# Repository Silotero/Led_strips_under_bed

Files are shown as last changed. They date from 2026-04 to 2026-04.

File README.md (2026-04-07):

# Led_strips_under_bed
Led strips that lights up according to the output of distance sensors.

The project uses 8 of HC-SR04 ultrasonic distance sensors to measure the distance beetween a detected project. They are separated into 2 zones, 4 sensors each. The 2 zones are at a 90 deegre angle (on a corner). Appropriate leds on the 2 led strips light up according to the readout of the sensors. There are 4 zones according to the distance:
-more than 115 cm - nothing lights up
-beetween 85 cm and 115 cm - light up blue
-beetween 55 cm and 85 cm - light up green
-beetween 22 cm and 55 cm - light up red

Everything is controlled via Atmega328p. The led strips are of WS2813 type.

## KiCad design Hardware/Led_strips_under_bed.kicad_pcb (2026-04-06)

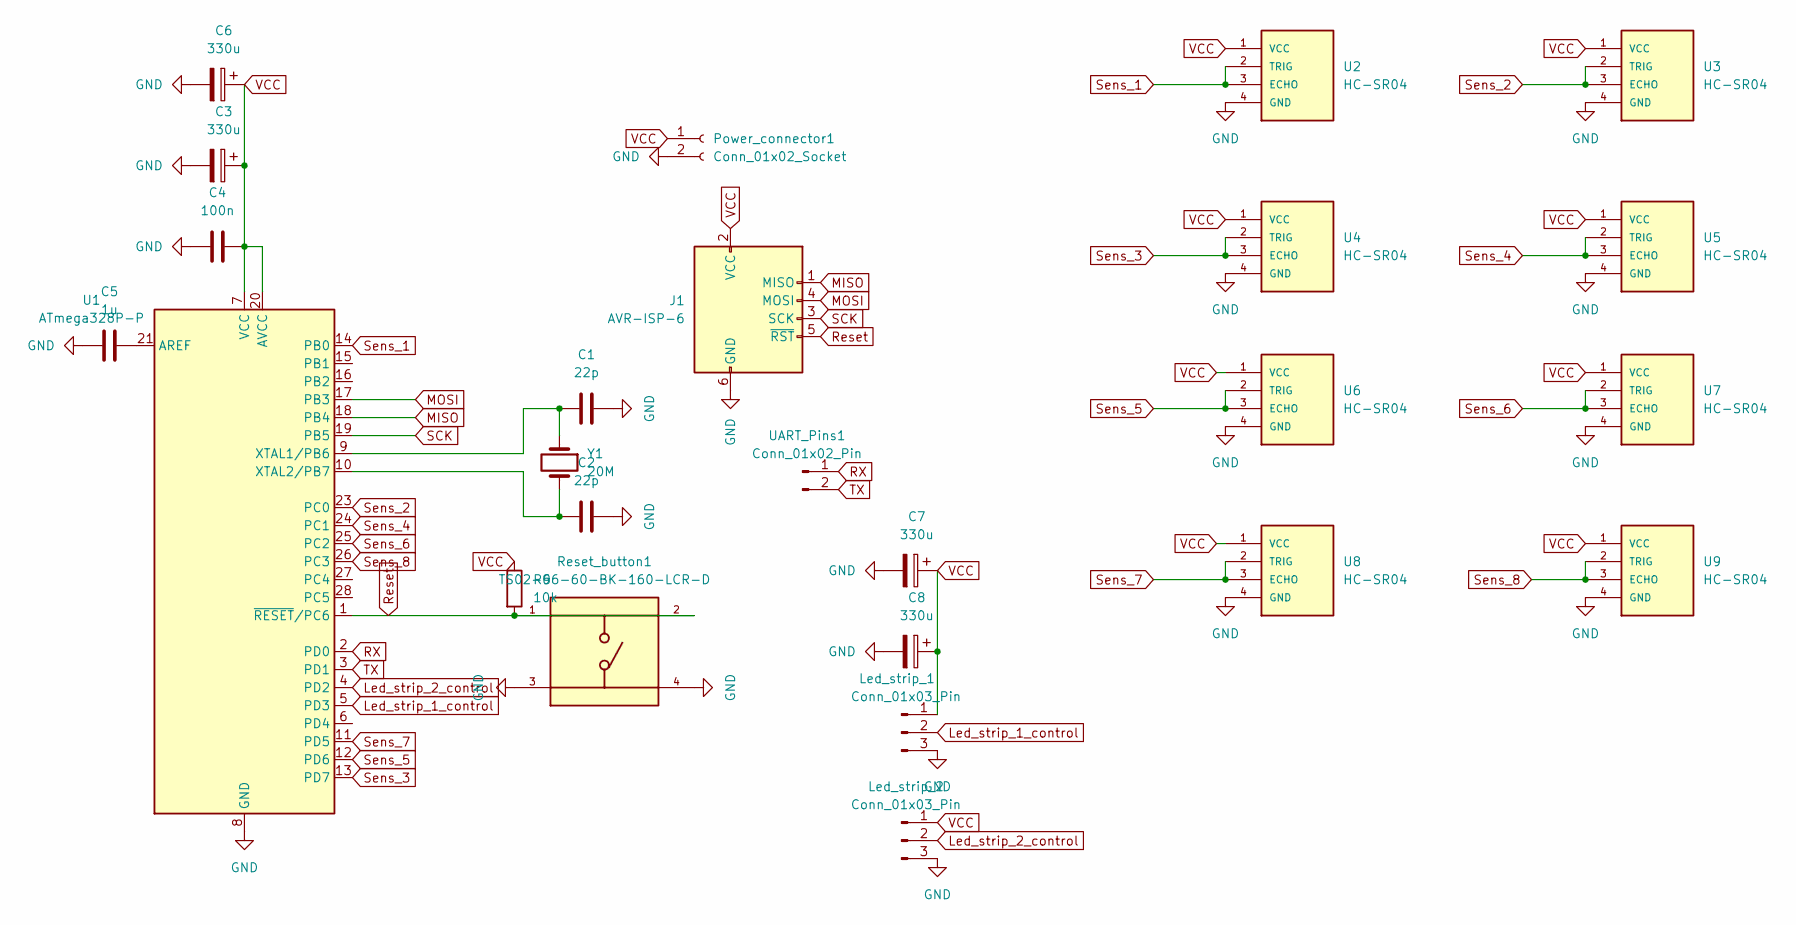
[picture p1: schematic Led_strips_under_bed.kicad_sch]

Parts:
C1, C2: 22p; C_0603_1608Metric
C3, C6, C7, C8: 330u; CP_Radial_D6.3mm_P2.50mm
C4: 100n; C_0603_1608Metric
C5: 1u; C_0603_1608Metric
J1: AVR-ISP-6; IDC-Header_2x03_P2.54mm_Vertical
Led_strip_1, Led_strip_2: Conn_01x03_Pin; PinHeader_1x03_P2.54mm_Vertical
Power_connector1: Conn_01x02_Socket; PinSocket_1x02_P2.54mm_Vertical
R9: 10k; R_0805_2012Metric
Reset_button1: TS02-66-60-BK-160-LCR-D; SW_TS02-66-60-BK-160-LCR-D; PARTREV 1.0
U1: ATmega328P-P; DIP-28_W7.62mm
U2, U3, U4, U5, U6, U7, U8, U9: HC-SR04; XCVR_HC-SR04
UART_Pins1: Conn_01x02_Pin; PinHeader_1x02_P2.54mm_Vertical
Y1: 20M; Resonator-2Pin_W7.0mm_H2.5mm

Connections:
GND: C1.2, C2.2, C3.2, C4.2, C5.2, C6.2, C7.2, C8.2, J1.6 (GND), Led_strip_1.3, Led_strip_2.3, Power_connector1.2, Reset_button1.3, Reset_button1.4, U1.8 (GND), U1.22 (GND), U2.4 (GND), U3.4 (GND), U4.4 (GND), U5.4 (GND), U6.4 (GND), U7.4 (GND), U8.4 (GND), U9.4 (GND); also elsewhere on the board
Led_strip_1_control: Led_strip_1.2, U1.5 (PD3)
Led_strip_2_control: Led_strip_2.2, U1.4 (PD2)
MISO: J1.1 (MISO), U1.18 (PB4)
MOSI: J1.4 (MOSI), U1.17 (PB3)
unnamed: C5.1, U1.21 (AREF)
unnamed: C1.1, U1.9 (XTAL1/PB6), Y1.1
unnamed: C2.1, U1.10 (XTAL2/PB7), Y1.2
RX: U1.2 (PD0), UART_Pins1.1
Reset: J1.5 (~RST), R9.2, Reset_button1.1, Reset_button1.2, U1.1 (~RESET/PC6); also elsewhere on the board
SCK: J1.3 (SCK), U1.19 (PB5)
Sens_1: U1.14 (PB0), U2.2 (TRIG), U2.3 (ECHO)
Sens_2: U1.23 (PC0), U3.2 (TRIG), U3.3 (ECHO)
Sens_3: U1.13 (PD7), U4.2 (TRIG), U4.3 (ECHO)
Sens_4: U1.24 (PC1), U5.2 (TRIG), U5.3 (ECHO)
Sens_5: U1.12 (PD6), U6.2 (TRIG), U6.3 (ECHO)
Sens_6: U1.25 (PC2), U7.2 (TRIG), U7.3 (ECHO)
Sens_7: U1.11 (PD5), U8.2 (TRIG), U8.3 (ECHO)
Sens_8: U1.26 (PC3), U9.2 (TRIG), U9.3 (ECHO)
TX: U1.3 (PD1), UART_Pins1.2
VCC: C3.1, C4.1, C6.1, C7.1, C8.1, J1.2 (VCC), Led_strip_1.1, Led_strip_2.1, Power_connector1.1, R9.1, U1.7 (VCC), U1.20 (AVCC), U2.1 (VCC), U3.1 (VCC), U4.1 (VCC), U5.1 (VCC), U6.1 (VCC), U7.1 (VCC), U8.1 (VCC), U9.1 (VCC)

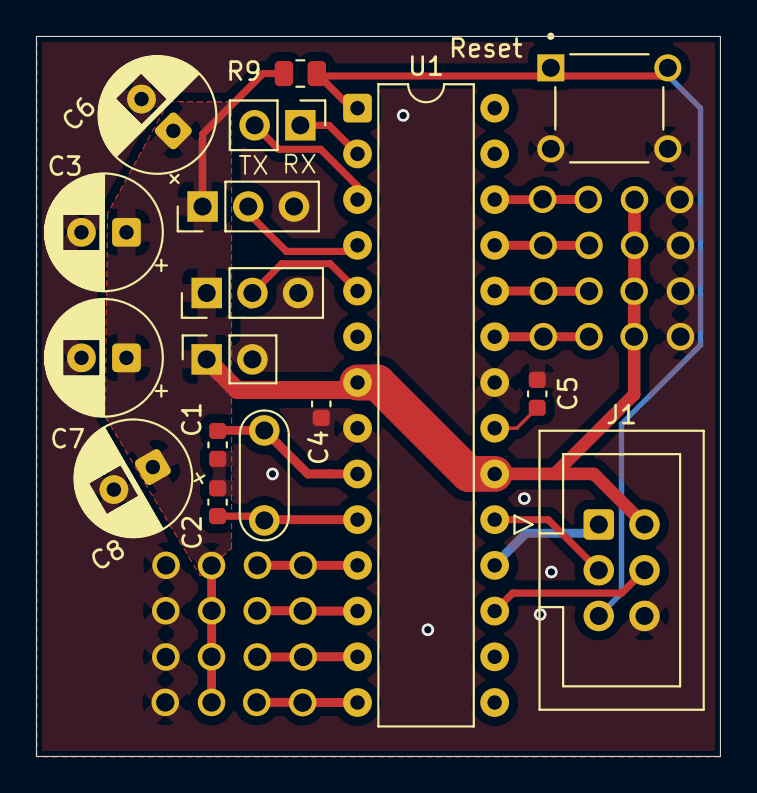
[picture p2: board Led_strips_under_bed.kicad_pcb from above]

Board: 2 copper layers, 38.0 x 40.0 mm, 25 parts (0 on the bottom side), 21 nets.

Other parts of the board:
Reset: TS02-66-60-BK-160-LCR-D; SW_TS02-66-60-BK-160-LCR-D

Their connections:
GND: Reset.3, Reset.4; also elsewhere on the board
Reset: Reset.1, Reset.2; also elsewhere on the board

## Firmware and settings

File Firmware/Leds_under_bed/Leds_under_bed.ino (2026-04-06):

#ifndef F_CPU
#define F_CPU 20000000UL
#endif
#include <avr/io.h>
#include <util/delay.h>
#include <stdbool.h>
#include <FastLED.h>
#include <UART_w_c.h>
#include <stdio.h>

#define NUM_LEDS 60 // number of used leds
#define DATA_PIN_STRIP_1 2 // pin for the led strip control
#define DATA_PIN_STRIP_2 3 // pin for the led strip control
#define NUM_SENSORS 8 // number of used distance sensors
#define MAX_DIST 200  // cm
#define CHIPSET WS2813
#define COLOR_ORDER BRG

#define CPU_FREQUENCY 20000000UL
#define BAUDRATE 9600

#define DEBUG 0

#if DEBUG
    #define DEBUG_uart_putchar (x) uart_putchar(x)
#endif

CRGB leds1[NUM_LEDS]; // array for holding values for the leds
CRGB leds2[NUM_LEDS]; // array for holding values for the leds

typedef struct {
    volatile uint8_t *ddr;
    volatile uint8_t *port;
    volatile uint8_t *pinx;
    uint8_t pin;
} Sensor_Pin;

const Sensor_Pin sensor_pins[] = {
    { &DDRD, &PORTD, &PIND, PD5 },
    { &DDRD, &PORTD, &PIND, PD6 },
    { &DDRD, &PORTD, &PIND, PD7 },
    { &DDRB, &PORTB, &PINB, PB0 },
    { &DDRC, &PORTC, &PINC, PC0 },
    { &DDRC, &PORTC, &PINC, PC1 },
    { &DDRC, &PORTC, &PINC, PC2 },
    { &DDRC, &PORTC, &PINC, PC3 },
};

long distances[NUM_SENSORS];
uint8_t counter = 0;

void timer1_init(void) {
    TCCR1A = 0;               // Normal mode
    TCCR1B = (1 << CS11);     // Prescaler 8 → 1 tick = 0.5 us @ 16 MHz, 1 us @ 8 MHz, 0,4 us @ 20 MHz
    TCNT1 = 0;                // Reset counter
}

long readDistance(volatile uint8_t *ddr, volatile uint8_t *port_out, volatile uint8_t *pinx_in, uint8_t pin) {
    // Set pin as output to send TRIG
    *ddr |= (1 << pin);       // Output
    *port_out &= ~(1 << pin);     // LOW
    _delay_us(2);
    *port_out |= (1 << pin);      // HIGH for 10us
    _delay_us(10);
    *port_out &= ~(1 << pin);     // LOW

    // Set pin as input to receive ECHO
    *ddr &= ~(1 << pin);      // Input
    *port_out &= ~(1 << pin);

    uint32_t counter = 0;
    while(!(*pinx_in & (1 << pin))) {   // Wait for pin to be high, meaning echo has started
        if(counter++ > 10000) return 0; 
    }
    TCNT1=0; // reset counter
    while(*pinx_in & (1<< pin)) {  // wait while pin is high meaning echo is still sending
        if(TCNT1 > 40000) break; // Max distance timeout
    }
    long duration= TCNT1; // read counter after echo has ended

    long distance = duration / 146; // = 0.034 speed of sound / 2 divide by 2 cause travel forth and back * 0.4 timing with the prescaler to get 1 us Convert echo duration to cm
    return distance;
}
void setup() {
    timer1_init();
    uart_init(CPU_FREQUENCY, BAUDRATE);
    FastLED.addLeds<CHIPSET, DATA_PIN_STRIP_1, COLOR_ORDER>(leds1, NUM_LEDS);
    FastLED.addLeds<CHIPSET, DATA_PIN_STRIP_2, COLOR_ORDER>(leds2, NUM_LEDS);
    FastLED.setBrightness(100);
}

void loop() {
    counter++;
    if (counter % 10 == 0) {
        FastLED.clear();
    }
    for (int i = 0; i < NUM_SENSORS; i++) {
        long combined_distance = 0;
        for (int j = 0; j < 3; j++) {
            combined_distance += readDistance(sensor_pins[i].ddr, sensor_pins[i].port, sensor_pins[i].pinx, sensor_pins[i].pin);
            _delay_ms(80);
        }
        distances[i] = combined_distance / 2;
        distances[i] = constrain(distances[i], 0, MAX_DIST);
        #if DEBUG
            char buffer[16];
            snprintf(buffer, sizeof(buffer), "%ld\n", distances[i]);
            for (char *p = buffer; *p; p++) {
                uart_putchar(*p);
            }
            uart_putchar('c');
            uart_putchar('m');
        #endif
        if (i < 4) {
            if (distances[i] < 55 && distances[i] > 22) {
                for (int j= 0; j < 15; j++) {
                leds1[i*15+j] =  CRGB::Red;
                }
            }
            else if (distances[i] < 85) {
                for (int j = 0; j < 15; j++) {
                leds1[i*15+j] =  CRGB::Green;
                }
            }
            else if (distances[i] < 115) {
                for (int j = 0; j < 15; j++) {
                leds1[i*15+j] =  CRGB::Blue;
                }
            }
        }
        else {
            if (distances[i] < 55 && distances[i] > 22) {
                for (int j = 0; j < 15; j++) {
                leds2[(i-4)*15+j] =  CRGB::Red;
                }
            }
            else if (distances[i] < 85) {
                for (int j = 0; j < 15; j++) {
                leds2[(i-4)*15+j] =  CRGB::Green;
                }
            }
            else if (distances[i] < 115) {
                for (int j = 0; j < 15; j++) {
                leds2[(i-4)*15+j] =  CRGB::Blue;
                }
            }
        }
        FastLED.show();
    }
}

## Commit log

2026-04-06 Update .gitignore
    Dodano ignorowanie folderów backups oraz gerber
2026-04-06 Finished project
    [Led_strips_under_bed.kicad_pcb, Led_strips_under_bed.kicad_sch]
2026-04-07 Update README.md
    Added the type of led strips (WS2813)
